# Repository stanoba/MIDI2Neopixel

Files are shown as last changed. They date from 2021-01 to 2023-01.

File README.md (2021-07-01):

# MIDI2Neopixel - Piano LED Visualizer

MIDI2Neopixel is simple Piano LED Visualizer based on Arduino pro micro (Leonardo) and LED strip WS2812B (144 LEDs / 1 m). It's compatible with [Synthesia](https://www.synthesiagame.com) piano learning software. 

In general, it could be also used with any music software allowing to define MIDI out device (e.g. NI Kontakt). 

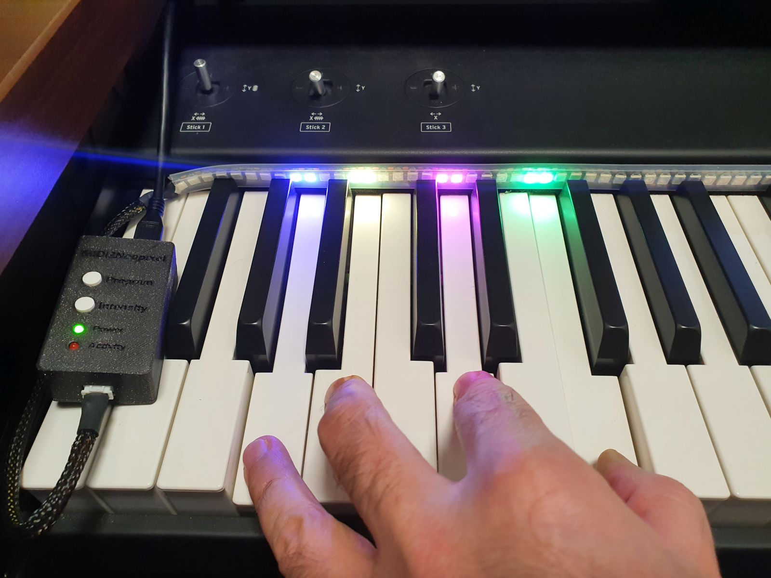
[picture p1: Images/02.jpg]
Piano


## Hardware
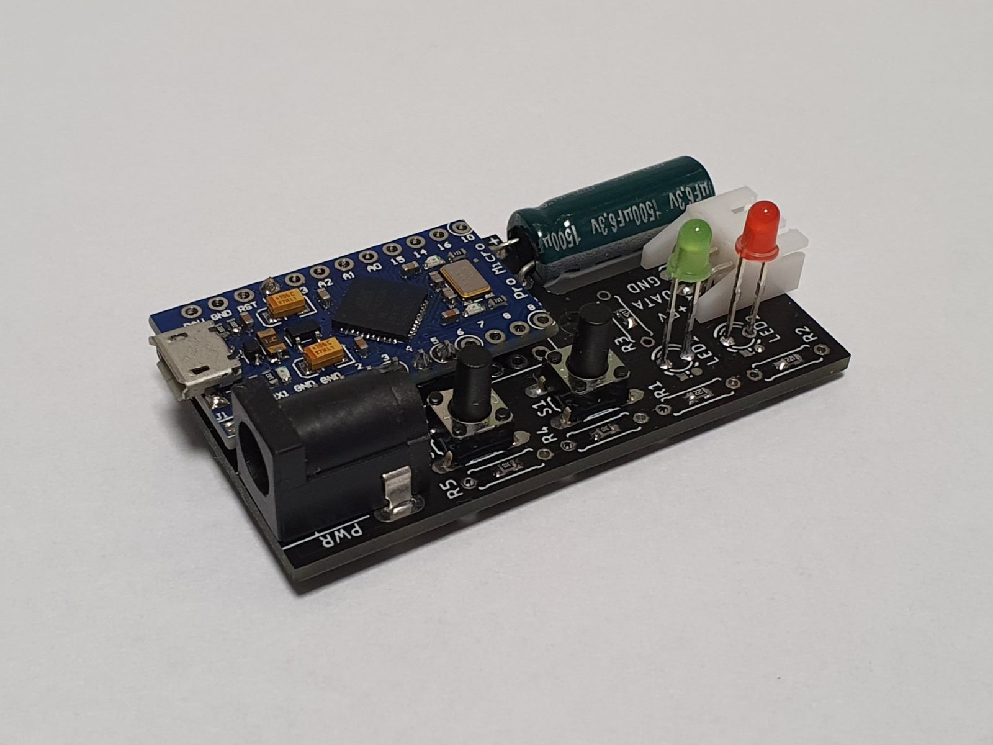
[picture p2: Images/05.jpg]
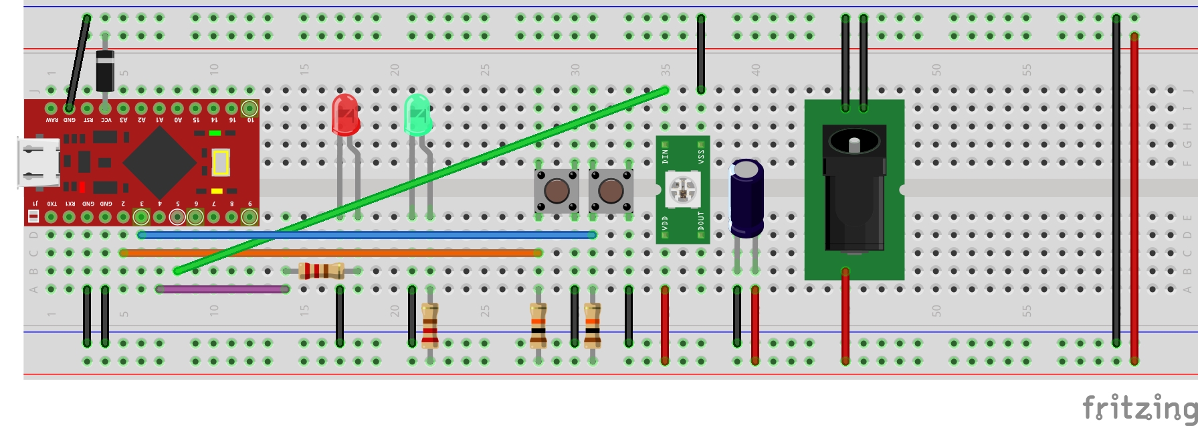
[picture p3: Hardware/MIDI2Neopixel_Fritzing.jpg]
 

See <a href="./Hardware">Hardware</a> README.md for more info.

## Software
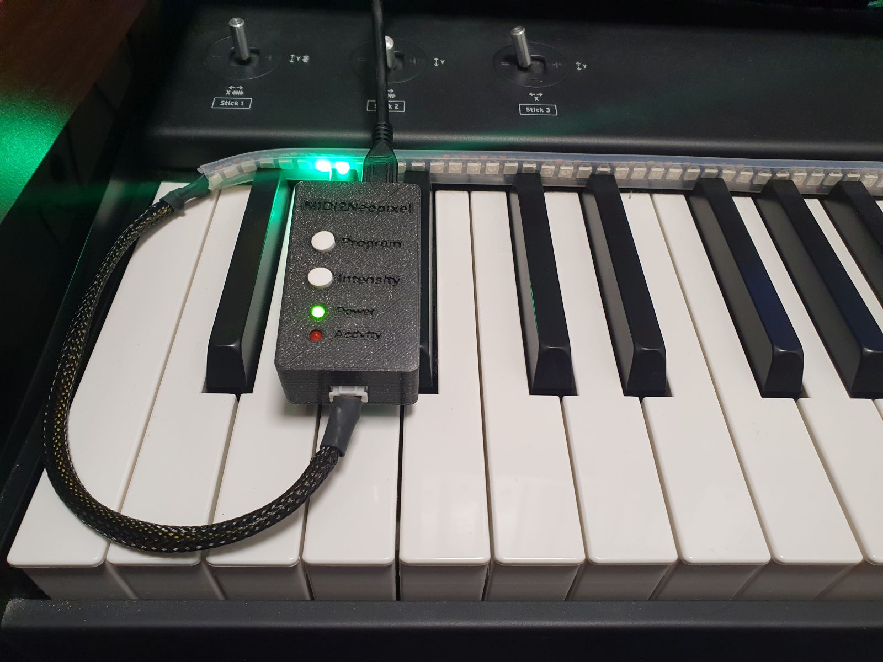
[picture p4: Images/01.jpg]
Software


See <a href="./Software">Software</a> README.md for more info.

## 3D printed parts
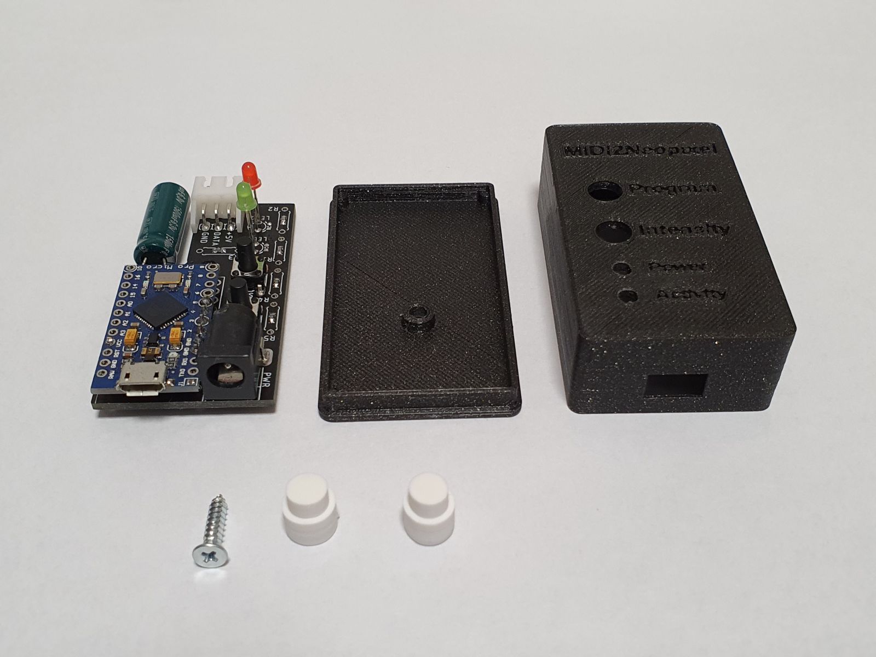
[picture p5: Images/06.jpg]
3D printed parts


See <a href="./3D models">3D models</a> README.md for more info.

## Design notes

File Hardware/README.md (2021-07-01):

# MIDI2Neopixel - Piano LED Visualizer - Hardware

Electronic is built on **Arduino pro micro** (Atmega 32u4) which behave as MIDI output device. It could be powered from 5V DC adapter or directly from USB port (limited amperage) after soldering schottky diode between Arduino PWR pin and + terminal of capacitor. LEDs used in project are WS2812B (144 LEDs / 1 m).

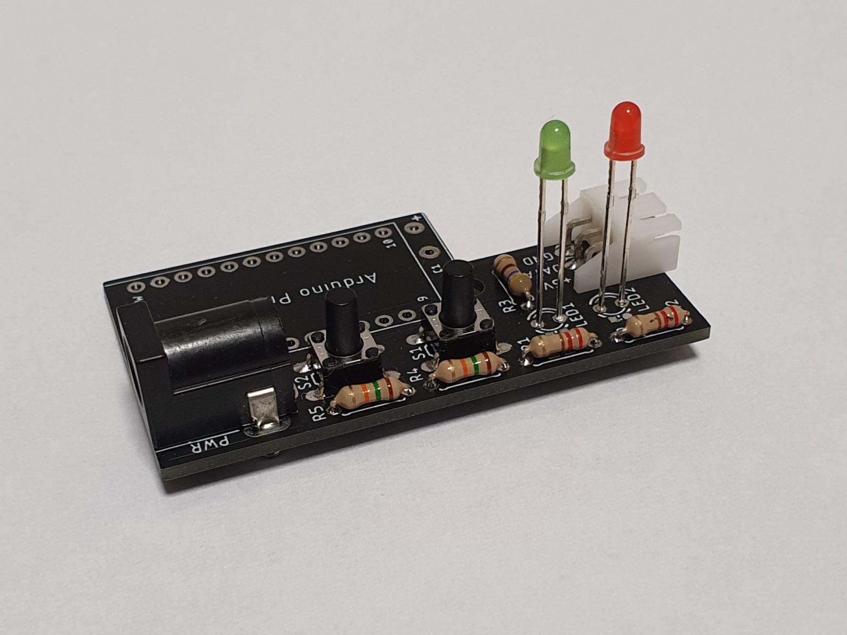
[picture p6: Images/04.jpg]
Board THT
<a href="../Images/05.jpg" target="_blank">Board SMD</a> 

PCB has place for SMD 0603 components or classic THT (You can select based on your supplies).

---
## Breadboard Example
<a href="MIDI2Neopixel_Fritzing.jpg" target="_blank">Fritzing</a>

---
## Schematic
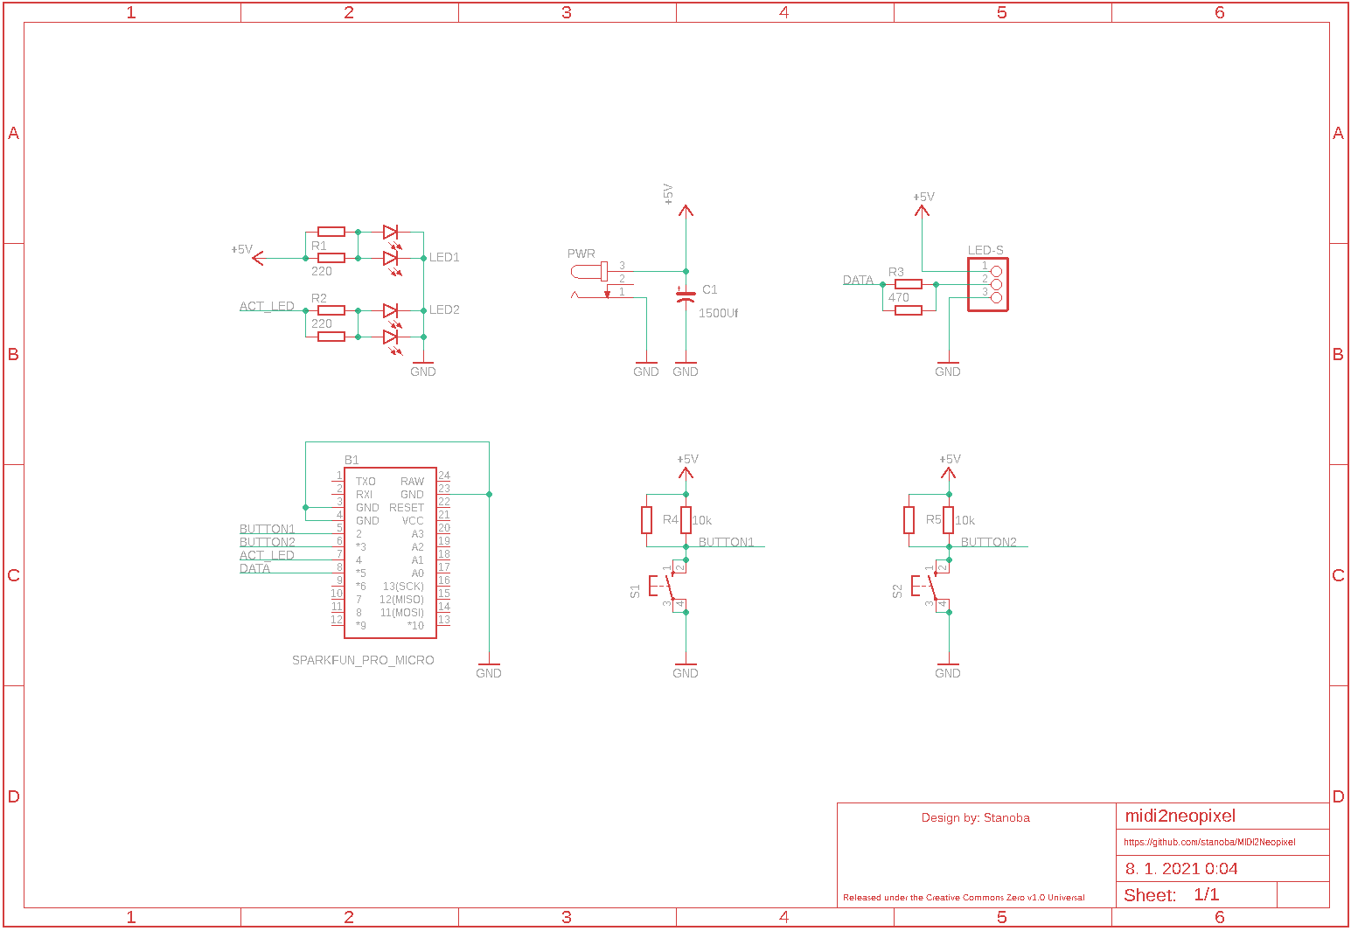
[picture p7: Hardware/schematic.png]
Schematic


## PCB

PCB was designed in Eagle 9.6.2:

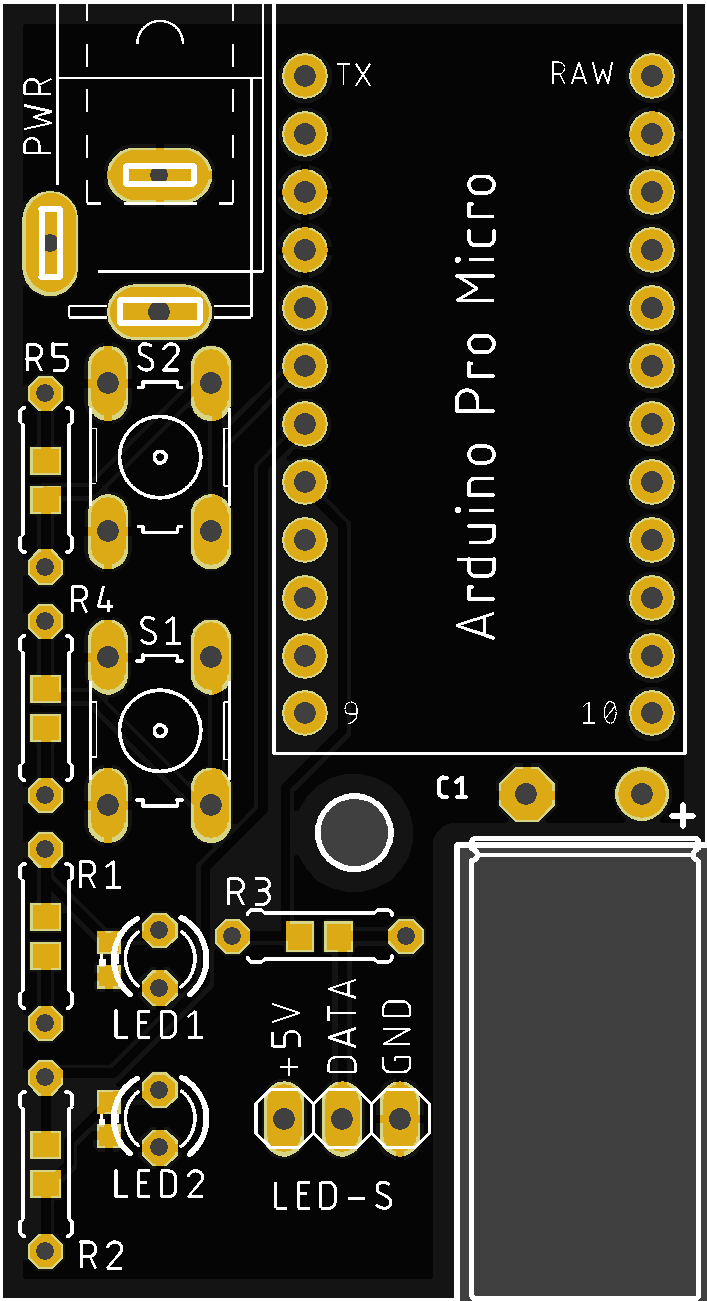
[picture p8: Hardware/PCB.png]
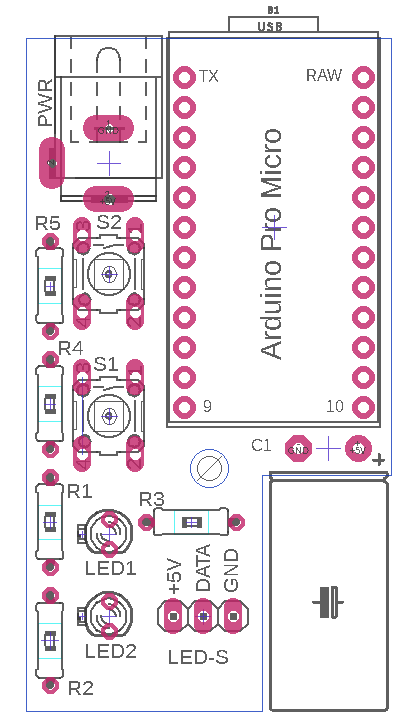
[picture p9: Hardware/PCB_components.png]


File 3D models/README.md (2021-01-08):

# MIDI2Neopixel - Piano LED Visualizer - 3D models

3D models could be also downladed from Thingiverse https://www.thingiverse.com/thing:4714197.

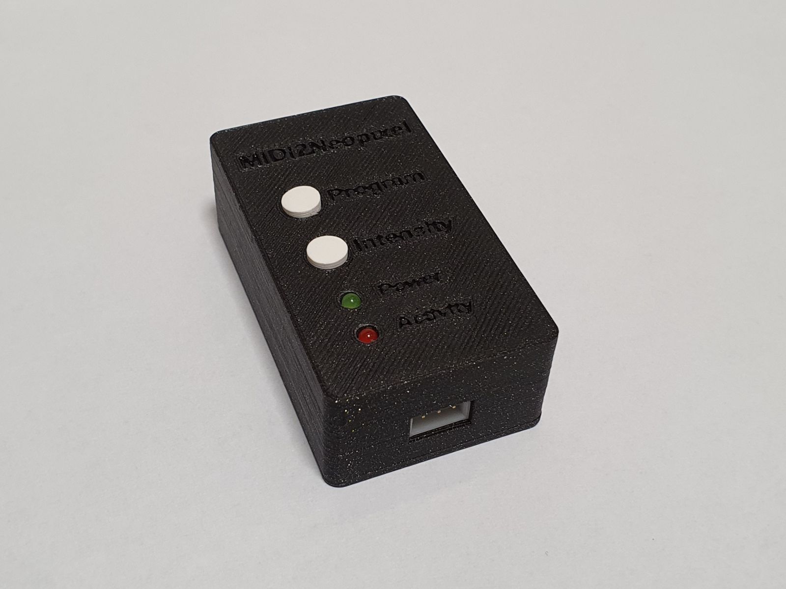
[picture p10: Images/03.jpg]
<a href="../Images/06.jpg" target="_blank">Schematic</a> 

**3D Printed parts:**
- 1x MIDI2Neopixel_case_bottom.stl
- 1x MIDI2Neopixel_case_top.stl
- 2x MIDI2Neopixel_case_button.stl

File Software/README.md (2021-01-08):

# MIDI2Neopixel - Piano LED Visualizer - Software

## Build and upload via Arduino IDE

1. Download prerequisities from https://github.com/FastLED/FastLED (version 3.3.3) and https://www.arduino.cc/en/Reference/MIDIUSB (version 1.0.4) to `Arduino/libraries` folder or via `Tools/Manage libraries` menu in IDE. 

2. Open source code in IDE and hit `Upload` button.

**Note:** If you want to use different USB device name instead of `Arduino Leonardo`, replace existing Arduino Leonardo name deffinition in `C:\Program Files (x86)\Arduino\hardware\arduino\avr\boards.txt` with `leonardo.name=MIDI2Neopixel` and `leonardo.build.usb_product="MIDI2Neopixel"`. Upload code, uninstall device `Arduino Leonardo` in Windows Device Manager and replug USB cable.

## Flash precompiled HEX to Arduino

If you have problem to compile code in Arduino IDE, you can directly flash precompiled firmware to `Arduino pro micro` board.

**Example:** `C:\Program Files (x86)\Arduino\hardware\tools\avr/bin/avrdude -CC:\Program Files (x86)\Arduino\hardware\tools\avr/etc/avrdude.conf -v -patmega32u4 -cavr109 -PCOM2 -b57600 -D -Uflash:w:MIDI2Neopixel.ino.hex:i`

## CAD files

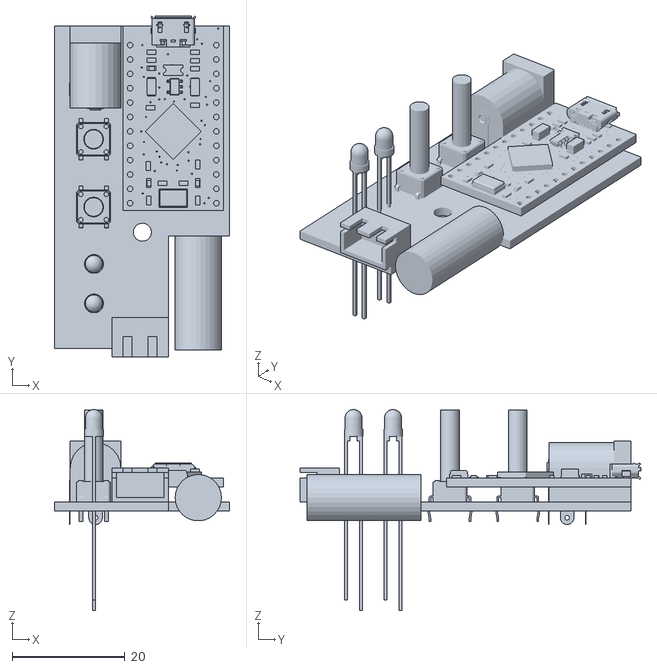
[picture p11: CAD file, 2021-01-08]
3D models/MIDI2Neopixel_PCB.stl
31.0 x 60.3 x 35.6

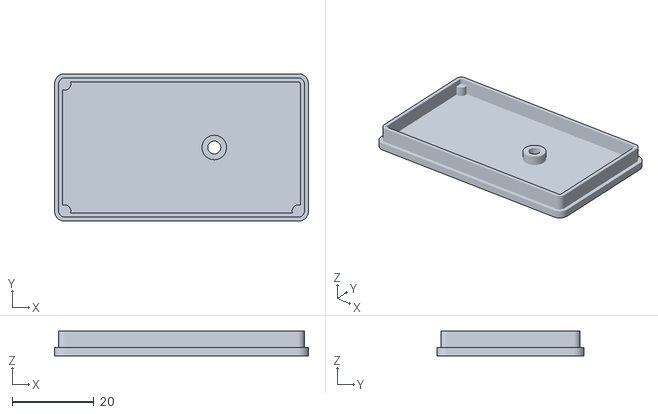
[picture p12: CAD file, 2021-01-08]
3D models/MIDI2Neopixel_case_bottom.stl
62.0 x 36.0 x 6.00

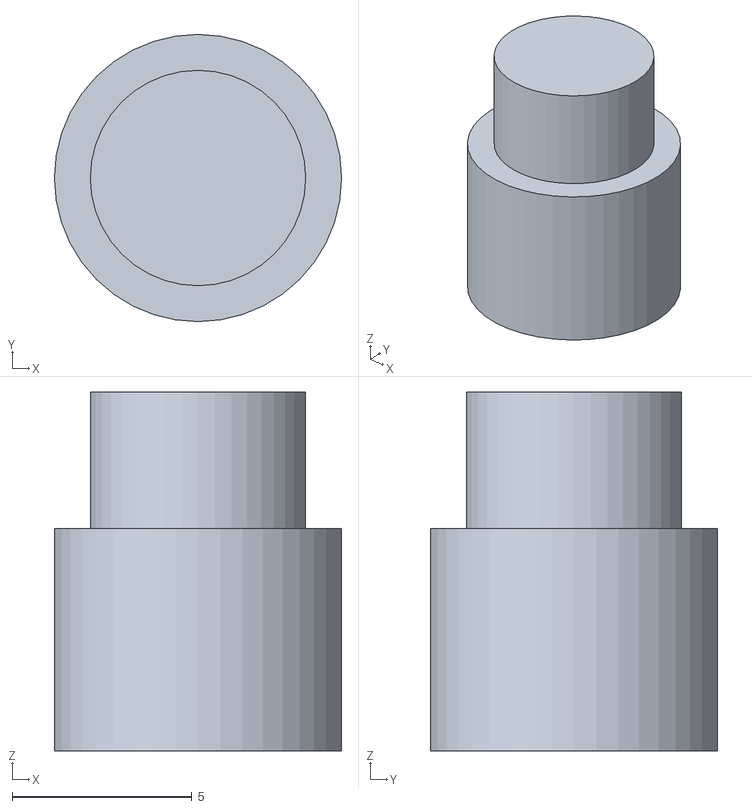
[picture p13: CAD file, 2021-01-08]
3D models/MIDI2Neopixel_case_button.stl
8.00 x 8.00 x 10.0

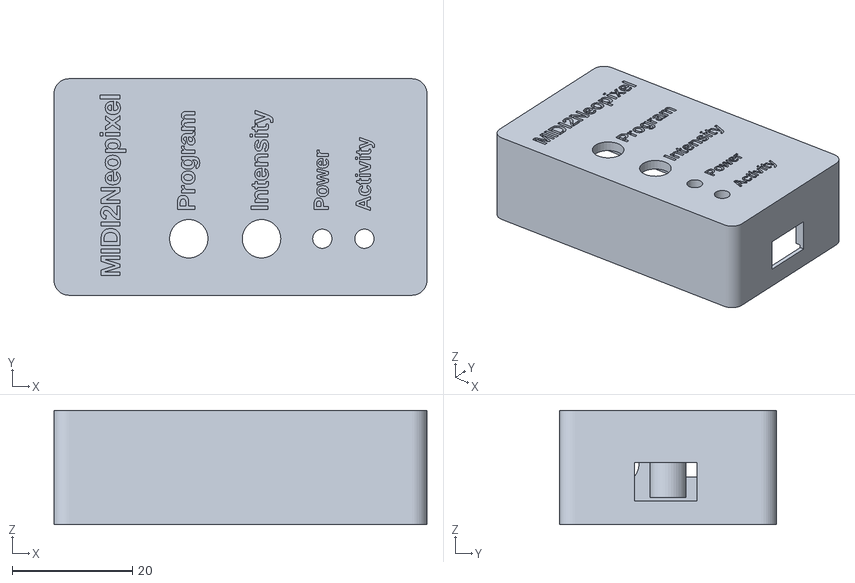
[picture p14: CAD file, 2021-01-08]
3D models/MIDI2Neopixel_case_top.stl
62.0 x 36.0 x 19.0

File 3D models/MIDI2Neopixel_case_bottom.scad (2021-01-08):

// MIDI2Neopixel case bottom
// by stanoba http://www.thingiverse.com/stanoba/about
// https://www.thingiverse.com/thing:4714197
// https://github.com/stanoba/MIDI2Neopixel

height = 36;
width = 62;
outside_radius=5;
depth=2;

/// PCB
translate([28.5,-13.3,6.2]) rotate([0,0,90]) color([0,1,0]) import("MIDI2Neopixel_PCB.stl", convexity=3);

module main(){
	difference(){
		union(){
			hull(){
				translate([ (width/2)-(outside_radius/2),(height/2)-(outside_radius/2),(depth/2)]) cylinder(h=depth,d=outside_radius, center=true, $fn=40);
				translate([(-width/2)+(outside_radius/2),(height/2)-(outside_radius/2),(depth/2)]) cylinder(h=depth,d=outside_radius, center=true, $fn=40);
				translate([(-width/2)+(outside_radius/2),(-height/2)+(outside_radius/2),(depth/2)]) cylinder(h=depth,d=outside_radius, center=true, $fn=40);
				translate([ (width/2)-(outside_radius/2),(-height/2)+(outside_radius/2),(depth/2)]) cylinder(h=depth,d=outside_radius, center=true, $fn=40);
			}
			
			hull(){
				translate([ (width/2)-(outside_radius/2),(height/2)-(outside_radius/2),(depth/2)+3]) cylinder(h=depth+2,d=3, center=true, $fn=40);
				translate([(-width/2)+(outside_radius/2),(height/2)-(outside_radius/2),(depth/2)+3]) cylinder(h=depth+2,d=3, center=true, $fn=40);
				translate([(-width/2)+(outside_radius/2),(-height/2)+(outside_radius/2),(depth/2)+3]) cylinder(h=depth+2,d=3, center=true, $fn=40);
				translate([ (width/2)-(outside_radius/2),(-height/2)+(outside_radius/2),(depth/2)+3]) cylinder(h=depth+2,d=3, center=true, $fn=40);
			}
		}
		pcb_space();
	}
	translate([ 8,0,3]) cylinder(h=3,d=6, center=true, $fn=40);
	//translate([ (width/2)-(outside_radius/2),(height/2)-(outside_radius/2) ,(depth/2)+2]) cylinder(h=3,d=3, center=true, $fn=40);
	translate([(-width/2)+(outside_radius/2),(height/2)-(outside_radius/2) ,(depth/2)+2]) cylinder(h=3,d=3, center=true, $fn=40);
	translate([(-width/2)+(outside_radius/2),(-height/2)+(outside_radius/2),(depth/2)+2]) cylinder(h=3,d=3, center=true, $fn=40);
	translate([ (width/2)-(outside_radius/2),(-height/2)+(outside_radius/2),(depth/2)+2]) cylinder(h=3,d=3, center=true, $fn=40);
}

module pcb_space(){
	hull(){
		translate([ (width/2)-(outside_radius/2),(height/2)-(outside_radius/2),(depth/2)+3]) cylinder(h=depth+2,d=1, center=true, $fn=40);
		translate([(-width/2)+(outside_radius/2),(height/2)-(outside_radius/2),(depth/2)+3]) cylinder(h=depth+2,d=1, center=true, $fn=40);
		translate([(-width/2)+(outside_radius/2),(-height/2)+(outside_radius/2),(depth/2)+3]) cylinder(h=depth+2,d=1, center=true, $fn=40);
		translate([ (width/2)-(outside_radius/2),(-height/2)+(outside_radius/2),(depth/2)+3]) cylinder(h=depth+2,d=1, center=true, $fn=40);
	}
}


module holes1(){
	translate([ 8,0,0]) cylinder(h=30,d=3.2, center=true, $fn=20);
	translate([ 8,0,1]) cylinder(h=2,d2=3.2,d1=6, center=true, $fn=20);
}



difference(){
	main();
	holes1();
	//holes2();
	
}

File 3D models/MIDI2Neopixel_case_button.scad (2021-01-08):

// MIDI2Neopixel case button
// by stanoba http://www.thingiverse.com/stanoba/about
// https://www.thingiverse.com/thing:4714197
// https://github.com/stanoba/MIDI2Neopixel

difference(){
	union(){
		translate([0,0,3.1]) cylinder(h=6.2,d=8, center=true, $fn=40);
		translate([0,0,5])    cylinder(h=10,d=6, center=true, $fn=40);
	}
	translate([0,0,2])    cylinder(h=4,d=3.8, center=true, $fn=30);
}

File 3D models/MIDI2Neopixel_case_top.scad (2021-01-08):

// MIDI2Neopixel case top
// by stanoba http://www.thingiverse.com/stanoba/about
// https://www.thingiverse.com/thing:4714197
// https://github.com/stanoba/MIDI2Neopixel

height = 36;
width = 62;
outside_radius=5;
depth=19;
font="Liberation Sans:style=Bold";
font_depth=1;

/// PCB
//translate([28.5,-13.3,4.2]) rotate([0,0,90]) color([0,1,0]) import("MIDI2Neopixel_PCB.stl", convexity=3);

// Case bottom
//translate([0,0,-2]) rotate([0,0,0]) color([1,0,0]) import("MIDI2Neopixel_case_bottom.stl", convexity=3);

module main(){
	difference(){
		union(){
			hull(){
				translate([ (width/2)-(outside_radius/2),(height/2)-(outside_radius/2),(depth/2)]) cylinder(h=depth,d=outside_radius, center=true, $fn=40);
				translate([(-width/2)+(outside_radius/2),(height/2)-(outside_radius/2),(depth/2)]) cylinder(h=depth,d=outside_radius, center=true, $fn=40);
				translate([(-width/2)+(outside_radius/2),(-height/2)+(outside_radius/2),(depth/2)]) cylinder(h=depth,d=outside_radius, center=true, $fn=40);
				translate([ (width/2)-(outside_radius/2),(-height/2)+(outside_radius/2),(depth/2)]) cylinder(h=depth,d=outside_radius, center=true, $fn=40);
			}
			
		}
		translate([ 0,0,-6 ]) pcb_space();

		hull(){
			translate([ (width/2)-(outside_radius/2)+0.1,(height/2)-(outside_radius/2) +0.1,2.25]) cylinder(h=4.5,d=3, center=true, $fn=40);
			translate([(-width/2)+(outside_radius/2)-0.1,(height/2)-(outside_radius/2) +0.1,2.25]) cylinder(h=4.5,d=3, center=true, $fn=40);
			translate([(-width/2)+(outside_radius/2)-0.1,(-height/2)+(outside_radius/2)-0.1,2.25]) cylinder(h=4.5,d=3, center=true, $fn=40);
			translate([ (width/2)-(outside_radius/2)+0.1,(-height/2)+(outside_radius/2)-0.1,2.25]) cylinder(h=4.5,d=3, center=true, $fn=40);
		}        

	}
	translate([ 8,0,11.5]) cylinder(h=14,d=6, center=true, $fn=40);
	//translate([ (width/2)-(outside_radius/2),(height/2)-(outside_radius/2) ,(depth/2)+2]) cylinder(h=3,d=3, center=true, $fn=40);
	//translate([(-width/2)+(outside_radius/2),(height/2)-(outside_radius/2) ,(depth/2)+2]) cylinder(h=14,d=3, center=true, $fn=40);
	translate([(-width/2)+(outside_radius/2),(-height/2)+(outside_radius/2),(depth/2)+2]) cylinder(h=14,d=3, center=true, $fn=40);
	translate([ (width/2)-(outside_radius/2),(-height/2)+(outside_radius/2),(depth/2)+2]) cylinder(h=14,d=3, center=true, $fn=40);
}

module pcb_space(){
	hull(){
		translate([ (width/2)-(outside_radius/2),(height/2)-(outside_radius/2),(depth/2)+3]) cylinder(h=depth+2,d=1, center=true, $fn=40);
		translate([(-width/2)+(outside_radius/2),(height/2)-(outside_radius/2),(depth/2)+3]) cylinder(h=depth+2,d=1, center=true, $fn=40);
		translate([(-width/2)+(outside_radius/2),(-height/2)+(outside_radius/2),(depth/2)+3]) cylinder(h=depth+2,d=1, center=true, $fn=40);
		translate([ (width/2)-(outside_radius/2),(-height/2)+(outside_radius/2),(depth/2)+3]) cylinder(h=depth+2,d=1, center=true, $fn=40);
	}
}



module holes(){
	// Screw
	translate([ 8,0,0]) cylinder(h=30,d=2.5, center=true, $fn=20);
	
	// LEDs
	translate([ 13.6,-8.6,15]) cylinder(h=30,d=3.2, center=true, $fn=30);
	translate([ 20.6,-8.6,15]) cylinder(h=30,d=3.2, center=true, $fn=30);
	
	// Buttons
	translate([ -8.6,-8.6,15])cylinder(h=30,d=6.4, center=true, $fn=30);
	translate([ 3.5,-8.6,15]) cylinder(h=30,d=6.4, center=true, $fn=30);
	
	// Power Jack
	translate([ (-width/2),-8.3,10.2]) rotate([0,90,0]) cylinder(h=5,d=7, center=true, $fn=30);

	// LED stripe connector
	translate([ (width/2),-0.4,7.1]) rotate([0,90,0]) cube([6.4,10.4,5],center=true);

	// micro USB connector
	translate([ (-width/2),5.4,9.6]) rotate([90,0,90]) microUSB();
	translate([ (-width/2)+1.5,5.5,6]) rotate([0,90,0]) cube([12,9,2],center=true);
}


module microUSB(){
	hull(){
		translate([ 2.6,0,0]) cylinder(h=5,d=3.4, center=true, $fn=30);
		translate([ -2.6,0,0]) cylinder(h=5,d=3.4, center=true, $fn=30);
	}
}

module labels(){
	translate([ -20, -15, depth-font_depth]) rotate([0,0,90]) linear_extrude(font_depth) text("MIDI2Neopixel", font = font, size = 3.3);

	translate([-7.6, -4, depth-font_depth]) rotate([0,0,90]) linear_extrude(font_depth) text("Program", font = font, size = 3);
	translate([ 4.6, -4, depth-font_depth]) rotate([0,0,90]) linear_extrude(font_depth) text("Intensity", font = font, size = 3);
	
	translate([14.6, -4, depth-font_depth]) rotate([0,0,90]) linear_extrude(font_depth) text("Power", font = font, size = 2.5);
	translate([21.6, -4, depth-font_depth]) rotate([0,0,90]) linear_extrude(font_depth) text("Activity", font = font, size = 2.5);
}


difference(){
	main();
	holes();
	labels();
}

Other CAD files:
3D models/MIDI2Neopixel_PCB.skp

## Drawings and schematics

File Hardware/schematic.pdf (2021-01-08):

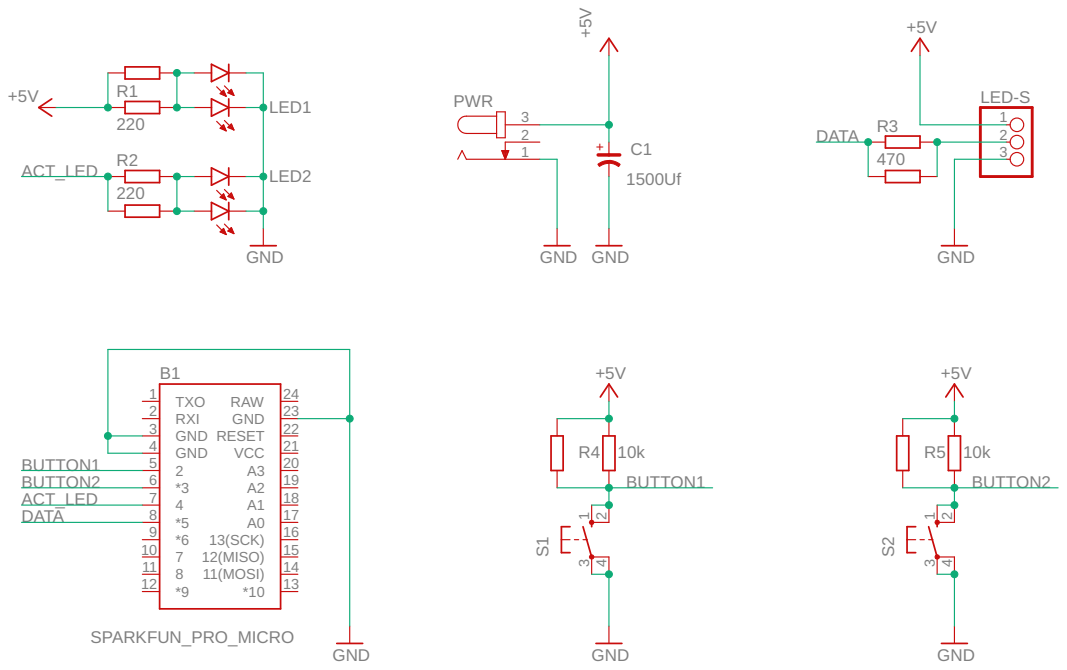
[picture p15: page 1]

https://github.com/stanoba/MIDI2Neopixel Released under the Creative Commons Zero v1.0 Universal

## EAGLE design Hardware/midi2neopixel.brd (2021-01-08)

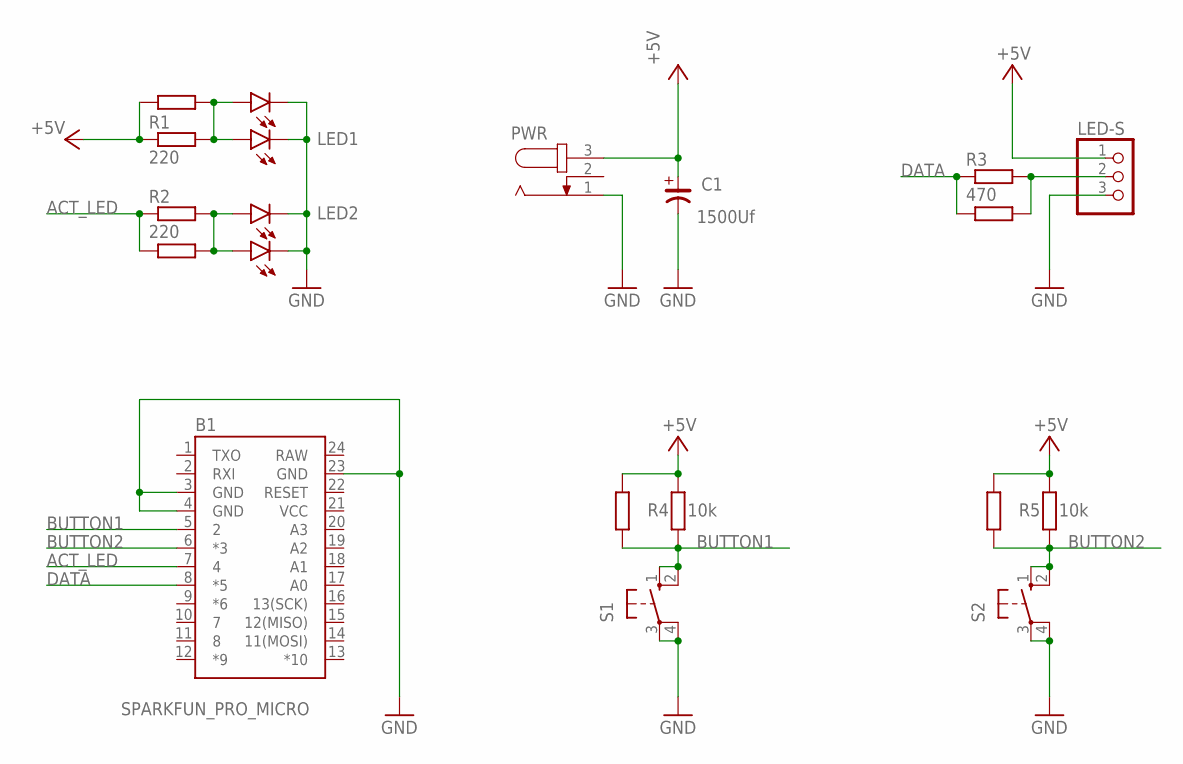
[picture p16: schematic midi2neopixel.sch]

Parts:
B1: SPARKFUN_PRO_MICRO
C1: 1500Uf; CEH-050-100X200
LED1: Green; LED3MM
LED2: Red; LED3MM
LED-S: PINHD-1X3; 1X03
LEDX1, LEDX2: LEDSML0603; SML0603
PWR: JACK-PLUG0; SPC4077
R1, R2: 220; 0207/7
R3: 470; 0207/7
R4, R5: 10k; 0207/7
RR1, RR2: 220; R0603
RR3: 470; R0603
RR4, RR5: 10k; R0603
S1, S2: 10-XX; B3F-10XX

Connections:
+5V: C1.+, LED-S.1, PWR.3, R1.1, R4.2, R5.2, RR1.1, RR4.2, RR5.2
ACT_LED: B1.7 (4), R2.1, RR2.1
BUTTON1: B1.5 (2), R4.1, RR4.1, S1.1 (S), S1.2 (S1)
BUTTON2: B1.6 (*3), R5.1, RR5.1, S2.1 (S), S2.2 (S1)
DATA: B1.8 (*5), R3.1, RR3.1
GND: B1.3 (GND), B1.4 (GND), B1.23 (GND), C1.-, LED1.K (C), LED2.K (C), LED-S.3, LEDX1.C, LEDX2.C, PWR.1, S1.3, S1.4 (P1), S2.3, S2.4 (P1)
unnamed: LED-S.2, R3.2, RR3.2
unnamed: LED1.A, LEDX1.A, R1.2, RR1.2
unnamed: LED2.A, LEDX2.A, R2.2, RR2.2
RAW: B1.24 (RAW)
VCC: B1.21 (VCC)

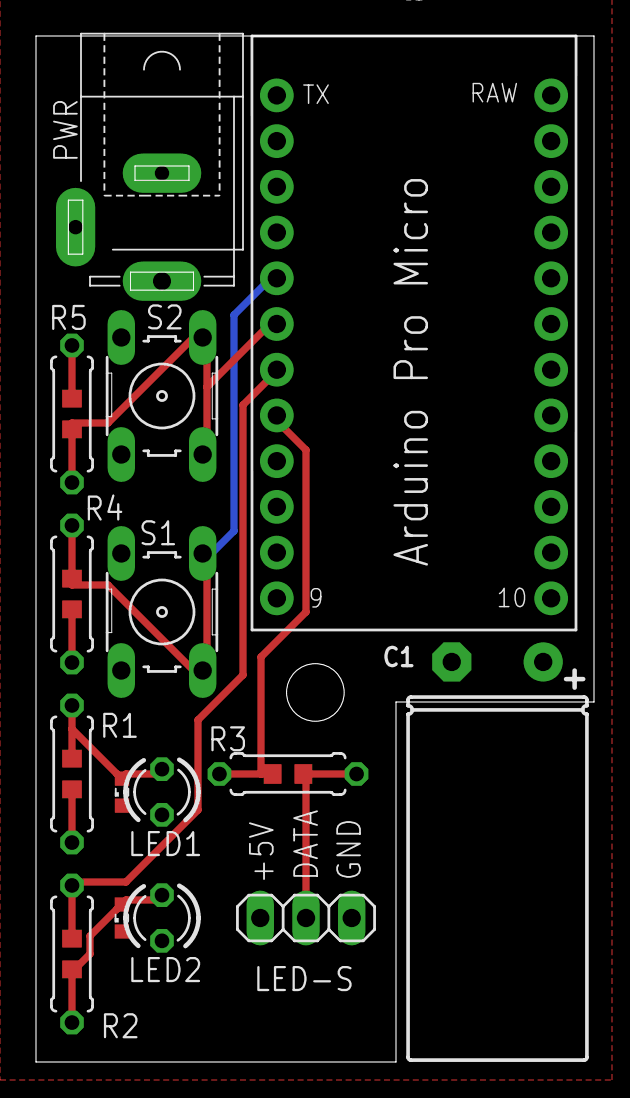
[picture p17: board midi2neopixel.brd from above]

Board: 2 copper layers, 31.0 x 57.0 mm, 20 parts (0 on the bottom side), 9 nets.

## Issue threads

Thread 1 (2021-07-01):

Compatibility with Apple iOS (iPad)

svanimisetti, 2021-07-01:
Thanks for sharing a great project. This is more of a question than an issue. Does this work with Apple devices? I have an iPad handy - which has Synthesia installed. Is it possible to upload/flash the firmware from Windows 10 into Pro Micro - and have it be recognized as a MIDI device from iPad? I don't think I will be able to connect the Pro Micro directly to the iPad - is there a converter or adapter required?

stanoba, 2021-07-02:
Hi @svanimisetti, I think it could work. Check issues in **MIDIUSB** library used in this project https://github.com/arduino-libraries/MIDIUSB/issues?q=is%3Aissue+ipad

There is also working MIDIUSB library example https://github.com/fab672000/MIDIUSB_1x1, which mentions in the code:
```
 *   Important Note: needs D_CONFIG macro in USBCore.h to be patched to change USB_CONFIG_POWER_MA(500)
 *     with a lower value (i.e 20) in order to work with iPad, as it is bus powered by the tablet.
```
Sorry, I'm not able to test it as I don't have iPhone, neither iPad.

svanimisetti, 2021-07-02:
Thanks @stanoba - I did not realize there is a configuration parameter. I agree - it seems to be a hardware issue. I am using a very old iPad for testing (its stuck on iOS 9!). Also, using a lightning-USB adapter I bought from Amazon. It might be that this is a fake or MFi-based clone. I will try to exchange that with a genuine apple accessory and see if I have any luck. I will report findings here.

svanimisetti, 2021-07-17:
Closing this issue - as multiple attempts did not resolve. I found that the issue is related to a faulty lightning-USB adapter. The first one I got was a clone and perhaps faulty. Replaced that with another one - but it now complains saying that ProMicro consumes too much power. This means I have to spend another 20$ to get the powered lighting-USB. For this kind of money just for an adapter, I am better of sticking to simpler solutions.

stanoba, 2021-07-17:
Maybe you can try to patch `USBCore.h` in Arduino IDE (C:\Program Files (x86)\Arduino\hardware\arduino\avr\cores\arduino) as mentioned above. On line 101 change `USB_CONFIG_POWER` from `500` to `20`. Compile code again and upload to ProMicro.

Closed 2021-07-17.

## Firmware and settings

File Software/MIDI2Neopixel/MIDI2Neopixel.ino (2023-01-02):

// Developed in Arduino IDE 1.8.13 (Windows)

#include <FastLED.h> // FastLED version 3.3.3 https://github.com/FastLED/FastLED
#include "MIDIUSB.h" // MIDIUSB version 1.0.4 https://www.arduino.cc/en/Reference/MIDIUSB

#define BUTTON_PIN1 3
#define BUTTON_PIN2 2
#define LED_ACT_PIN 4
#define LED_PIN     5
#define NUM_LEDS    144
#define LED_TYPE    WS2812B
#define COLOR_ORDER GRB
#define AMPERAGE    1500     // Power supply amperage in mA

#define NOTE_OFFSET   29     // Offset of first note from left (depends on Piano)
#define LEDS_PER_NOTE 2      // How many LED are on per key
#define LED_INT_STEPS 8      // LED Intensity button steps

#define DEBUG

CRGB leds[NUM_LEDS];
byte color = 0xFFFFFF;
int ledProgram = 1;
int ledIntensity = 2;  // default LED brightness
int ledBrightness = ceil(255 / LED_INT_STEPS * ledIntensity); // default LED brightness
int buttonState1;
int buttonState2;
int lastButtonState1 = LOW;
int lastButtonState2 = LOW;
unsigned long lastDebounceTime1 = 0;
unsigned long lastDebounceTime2 = 0;
unsigned long debounceDelay = 50;

//------------------------------------------- FUNCTIONS ----------------------------------------------//

const char* pitch_name(byte pitch) {
  static const char* names[] = {"C", "C#", "D", "D#", "E", "F", "F#", "G", "G#", "A", "A#", "B"};
  return names[pitch % 12];
}

int pitch_octave(byte pitch) {
  return (pitch / 12) - 1;
}

void SetNote(byte pitch, CRGB color) {
  int b = 0;
  for (int a = 0; a < LEDS_PER_NOTE; a++) {
    //if (int(pitch) > 66){b=1;}else{b=0;} // led stripe solder joints compensation
    leds[(((pitch - NOTE_OFFSET)*LEDS_PER_NOTE)+ a - b)]= color;
  }
}

void SetNote2(byte pitch, int hue) {
  int b = 0;
  for (int a = 0; a < LEDS_PER_NOTE; a++) {
    //if (int(pitch) > 66){b=1;}else{b=0;} // led stripe solder joints compensation
    leds[(((pitch - NOTE_OFFSET)*LEDS_PER_NOTE)+a - b)].setHSV(hue, 255, 255);
  }
}

void noteOn(byte channel, byte pitch, byte velocity) {
  if (velocity > 0) {
    switch (channel) {

      // Left Hand
    case 144: // Default Channel is 144
    case 155:
    case 145 ... 149:
      if (ledProgram == 1){
        SetNote(pitch,0x0000FF);
      }else if (ledProgram == 2){
        SetNote(pitch,0x00FF00);
      }else if (ledProgram == 3){
        SetNote2(pitch,pitch*velocity);
      }else if (ledProgram == 4){
        SetNote2(pitch,velocity*2);
      }else if (ledProgram == 5){
        SetNote(pitch,0xFFFFFF);
      }else if (ledProgram == 6){
        SetNote2(pitch,ceil((pitch-NOTE_OFFSET) * (255/(NUM_LEDS/LEDS_PER_NOTE))));
      }else{
      }
      break;
      
      // Right Hand
    case 156:
    case 150 ... 154:
      SetNote(pitch,0x00FF00);
      break;
      
    default:
      SetNote(pitch,0xFFFFFF);
      break;
    }

    if (DEBUG == true){     Serial.println("Note ON   - Channel:" + String(channel) + " Pitch:" + String(pitch) + " Note:" + pitch_name(pitch) + String(pitch_octave(pitch)) + " Velocity:" + String(velocity)); }
  }else{   
    SetNote(pitch,0x000000); // black
    if (DEBUG == true){     Serial.println("Note OFF2 - Channel:" + String(channel) + " Pitch:" + String(pitch) + " Note:" + pitch_name(pitch) + String(pitch_octave(pitch)) + " Velocity:" + String(velocity)); }
  }
  FastLED.show();
}

void noteOff(byte channel, byte pitch, byte velocity) {
  if (ledProgram == 5){
    fill_rainbow( leds, NUM_LEDS, 0, 5);
  }else{
    SetNote(pitch,0x000000); // black
  }

  #ifdef DEBUG
  Serial.print("Note OFF  - Channel:");
  Serial.print(String(channel));
  Serial.print(" Pitch:");
  Serial.print(String(pitch));
  Serial.print(" Note:");
  Serial.print(pitch_name(pitch) + String(pitch_octave(pitch)));
  Serial.print(" Velocity:");
  Serial.println(String(velocity));
  #endif
  FastLED.show();
}

void controlChange(byte channel, byte control, byte value) {
  #ifdef DEBUG
  Serial.print("Control  - Channel:");
  Serial.print(String(channel));
  Serial.print(" Control:");
  Serial.print(String(control));
  Serial.print(" Value:");
  Serial.println(String(value));
  #endif
}

//-------------------------------------------- SETUP ----------------------------------------------//

void setup() {
  #ifdef DEBUG
  Serial.begin(115200);
  #endif
  delay( 3000 ); // power-up safety delay
  FastLED.setMaxPowerInVoltsAndMilliamps(5, AMPERAGE);
  pinMode(BUTTON_PIN1, INPUT_PULLUP);
  pinMode(BUTTON_PIN2, INPUT_PULLUP);
  pinMode(LED_ACT_PIN, OUTPUT);
  FastLED.addLeds<LED_TYPE, LED_PIN, COLOR_ORDER>(leds, NUM_LEDS).setCorrection( TypicalLEDStrip );
  FastLED.setBrightness(ledBrightness);
  fill_solid( leds, NUM_LEDS, CRGB(0,0,0));
  SetNote(NOTE_OFFSET+ledProgram-1,0xFF0000);
  FastLED.show();
  #ifdef DEBUG
  Serial.println("MIDI2Neopixel is ready!");
  #endif
}

//--------------------------------------------- LOOP ----------------------------------------------//
void loop() {
  ////////////////////////////////////////////// Button 1 /////////////////////////////////////////////

  int reading1 = digitalRead(BUTTON_PIN1);

  if (reading1 != lastButtonState1) {
    lastDebounceTime1 = millis();
  }

  if ((millis() - lastDebounceTime1) > debounceDelay) {
    if (reading1 != buttonState1) {
      buttonState1 = reading1;

      // only toggle the LED if the new button state is HIGH
      if (buttonState1 == LOW) {
        ledProgram++;
        if (ledProgram>6){
          ledProgram = 1;
        }
        if (DEBUG == true){     Serial.println("Button 1 pressed! Program is " + String(ledProgram)); }
        // Set LED indication for program
        fill_solid( leds, NUM_LEDS, CRGB(0,0,0));
        SetNote(NOTE_OFFSET+ledProgram-1,0xFF0000);
        FastLED.show();
      }
    }
  }

  ////////////////////////////////////////////// Button 2 /////////////////////////////////////////////

  int reading2 = digitalRead(BUTTON_PIN2);

  if (reading2 != lastButtonState2) {
    lastDebounceTime2 = millis();
  }

  if ((millis() - lastDebounceTime2) > debounceDelay) {
    if (reading2 != buttonState2) {
      buttonState2 = reading2;

      // only toggle the LED if the new button state is HIGH
      if (buttonState2 == LOW) {
        ledIntensity++;
        SetNote(NOTE_OFFSET+ledIntensity-2,0x000000);
        if (ledIntensity>LED_INT_STEPS){
          ledIntensity = 1;
        }
        // Map ledIntensity to ledBrightness
        ledBrightness = map(ledIntensity, 1, LED_INT_STEPS, 3, 255);
        FastLED.setBrightness(ledBrightness);
        #ifdef DEBUG
        Serial.print("Button 2 pressed! Intensity is ");
        Serial.print(String(ledIntensity));
        Serial.print(" and brightness to ");
        Serial.print(String(ledBrightness));
        #endif
        // Set LED indication for program
        SetNote(NOTE_OFFSET+ledIntensity-1,0x00FF00);
        FastLED.show();
      }
    }
  }

  ////////////////////////////////////////// MIDI Read routine ////////////////////////////////////////
  midiEventPacket_t rx = MidiUSB.read();
  if (rx.header) {digitalWrite(LED_ACT_PIN, HIGH);}
  switch (rx.header) {
  case 0:
    break; //No pending events
    
  case 0x9:
    noteOn(rx.byte1,rx.byte2,rx.byte3);
    break;
    
  case 0x8:
    noteOff(rx.byte1,rx.byte2,rx.byte3);
    break;
    
  case 0xB:
    controlChange(rx.byte1 & 0xF,rx.byte2,rx.byte3);
    break;
    
  default:
    #ifdef DEBUG
    Serial.print("Unhandled MIDI message: ");
    Serial.print(rx.header, HEX);
    Serial.print("-");
    Serial.print(rx.byte1, HEX);
    Serial.print("-");
    Serial.print(rx.byte2, HEX);
    Serial.print("-");
    Serial.println(rx.byte3, HEX);
    #endif
    break;
  }


  if (rx.header) {digitalWrite(LED_ACT_PIN, LOW);}
  lastButtonState1 = reading1;
  lastButtonState2 = reading2;
}
//------------------------------------------ END OF LOOP -------------------------------------------//

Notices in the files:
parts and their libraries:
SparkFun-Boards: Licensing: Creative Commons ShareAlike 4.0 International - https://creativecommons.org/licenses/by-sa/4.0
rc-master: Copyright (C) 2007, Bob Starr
